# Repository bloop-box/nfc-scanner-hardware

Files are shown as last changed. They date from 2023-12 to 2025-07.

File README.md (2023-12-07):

# Bloop NFC Scanner Hardware



3D Render

[Documentation](https://bloop-box.github.io/nfc-scanner-hardware)

Connect an RC522 based NFC-Reader to your computer using USB

The project is based around a Raspberry Pi [RP2040](https://www.raspberrypi.com/documentation/microcontrollers/rp2040.html) microcontroller. It would have been possible to solve this with a much simpler controller but availability and pricing at the time of development as well as ease of use made the RP2040 with built in USB the best choice. 

The board is designed using KiCAD 6 with production and assembly by JLCPCB in mind. All parts are selected to be available from JLCPCB at the time of writing and as many parts as possible are used from their basic library.

## Case
A simple case design can be found in the case subfolder. It fits when the two boards are connected with standard angled 2.54mm pitch connectors as seen in the picture. 

The two halves can be connected with self-tapping, countersunk M3x6 screws

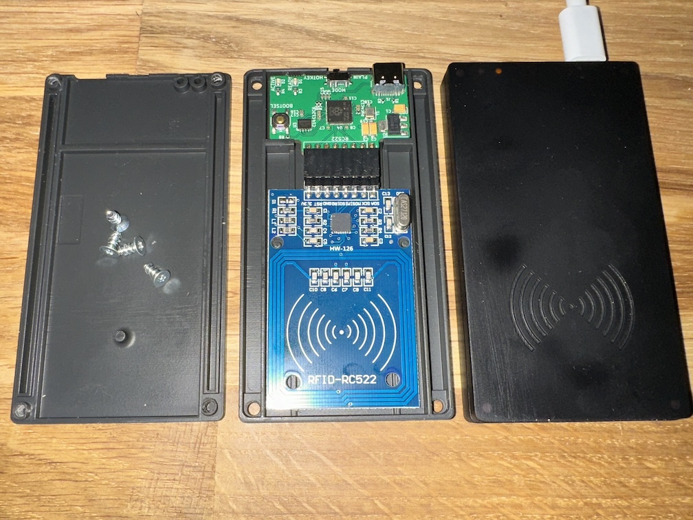
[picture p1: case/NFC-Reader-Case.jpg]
Case


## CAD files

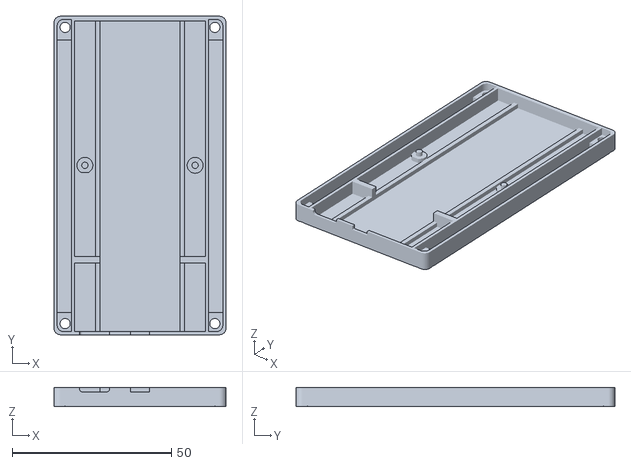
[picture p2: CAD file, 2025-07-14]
case/NFC-Reader-Case-Bottom.stl
54.0 x 100.0 x 6.00

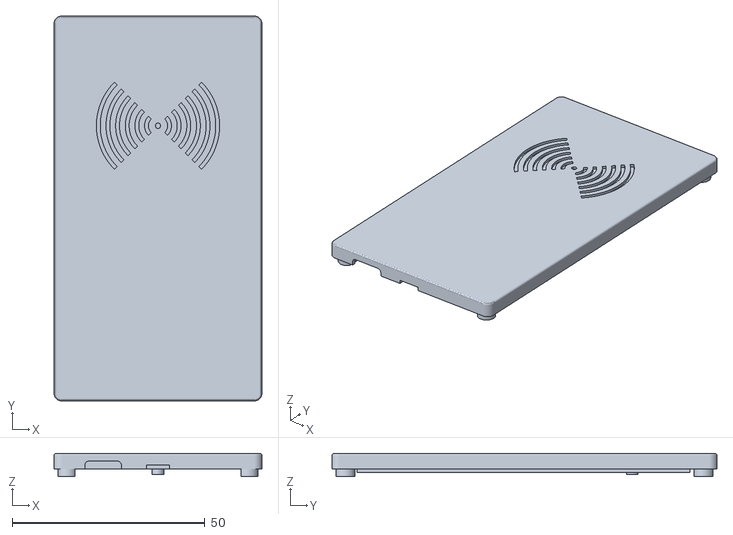
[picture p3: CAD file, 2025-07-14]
case/NFC-Reader-Case-Top.stl
54.0 x 100.0 x 6.00

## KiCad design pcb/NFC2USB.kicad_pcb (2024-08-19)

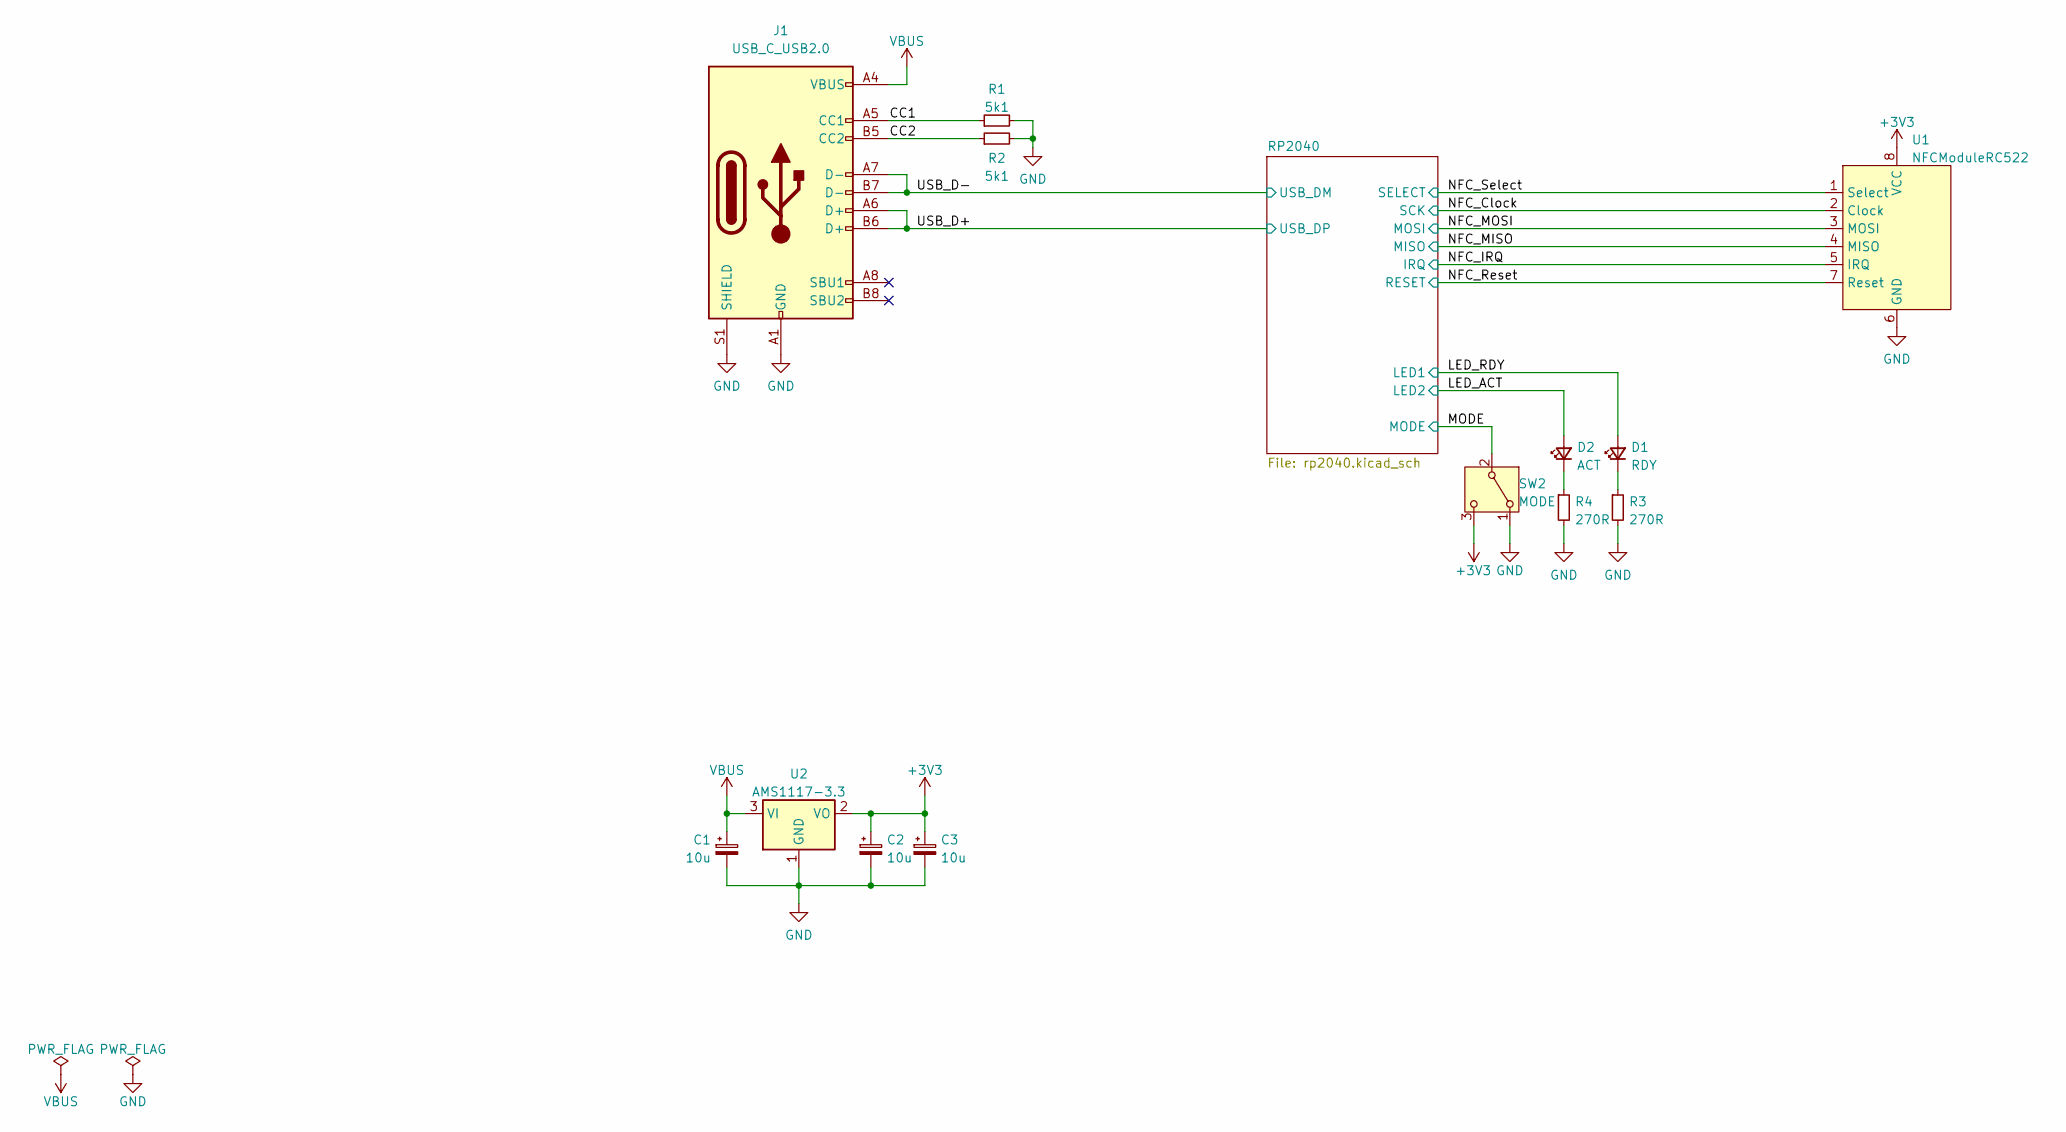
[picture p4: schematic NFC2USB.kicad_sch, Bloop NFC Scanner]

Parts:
C1, C2, C3: 10u; CP_EIA-3216-18_Kemet-A; LCSC C7171
D1: RDY; LED_0603_1608Metric; LCSC C72038
D2: ACT; LED_0603_1608Metric; LCSC C72043
J1: USB_C_USB2.0; USB_C_Receptacle_HRO_TYPE-C-31-M-12; LCSC C2894897
R1, R2: 5k1; R_0402_1005Metric; LCSC C25905
R3, R4: 270R; R_0603_1608Metric; LCSC C22966
SW2: MODE; SW_SPDT_PCM12; LCSC C431541
U1: NFCModuleRC522; PinSocket_1x08_P2.54mm_Vertical; LCSC C2897390
U2: AMS1117-3.3; SOT-223-3_TabPin2; LCSC C6186

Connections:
+3V3: C2.1, C3.1, SW2.3 (C), U1.8 (VCC), U2.2 (VO); also elsewhere on the board
/CC1: J1.A5 (CC1), R1.1
/CC2: J1.B5 (CC2), R2.1
/LED_ACT: D2.2 (A); also elsewhere on the board
/LED_RDY: D1.2 (A); also elsewhere on the board
/MODE: SW2.2 (B); also elsewhere on the board
/NFC_Clock: U1.2 (Clock); also elsewhere on the board
/NFC_IRQ: U1.5 (IRQ); also elsewhere on the board
/NFC_MISO: U1.4 (MISO); also elsewhere on the board
/NFC_MOSI: U1.3 (MOSI); also elsewhere on the board
/NFC_Reset: U1.7 (Reset); also elsewhere on the board
/NFC_Select: U1.1 (Select); also elsewhere on the board
/USB_D+: J1.A6 (D+), J1.B6 (D+); also elsewhere on the board
/USB_D-: J1.A7 (D-), J1.B7 (D-); also elsewhere on the board
GND: C1.2, C2.2, C3.2, J1.A1 (GND), J1.A12 (GND), J1.B1 (GND), J1.B12 (GND), J1.S1 (SHIELD), R1.2, R2.2, R3.2, R4.2, SW2.1 (A), U1.6 (GND), U2.1 (GND); also elsewhere on the board
unnamed: D1.1 (K), R3.1
unnamed: D2.1 (K), R4.1
VBUS: C1.1, J1.A4 (VBUS), J1.A9 (VBUS), J1.B4 (VBUS), J1.B9 (VBUS), U2.3 (VI)

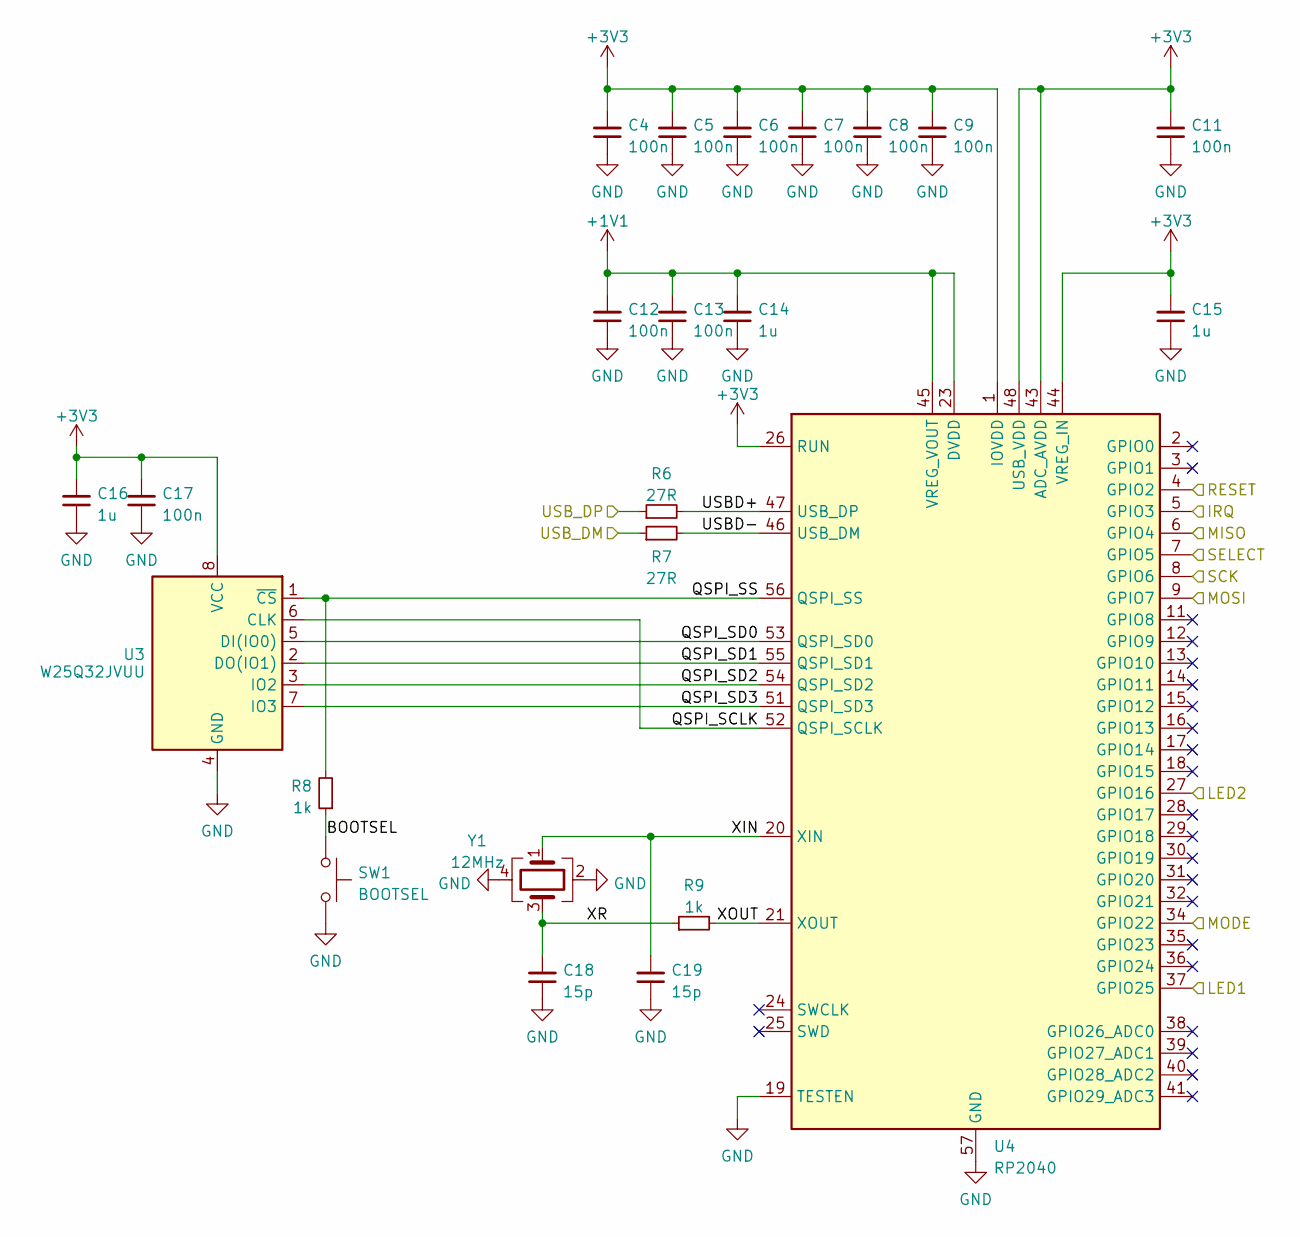
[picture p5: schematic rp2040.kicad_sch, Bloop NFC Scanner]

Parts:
C4, C5, C6, C7, C8, C9, C11, C12, C13, C17: 100n; C_0402_1005Metric; LCSC C1525
C14, C15, C16: 1u; C_0402_1005Metric; LCSC C52923
C18, C19: 15p; C_0402_1005Metric; LCSC C1548
R6, R7: 27R; R_0402_1005Metric; LCSC C25100
R8, R9: 1k; R_0402_1005Metric; LCSC C11702
SW1: BOOTSEL; SW_SPST_TL3342; LCSC C318884
U3: W25Q32JVUU; USON8 (3x4); LCSC C2999380
U4: RP2040; QFN-56-1EP_7x7mm_P0.4mm_EP3.2x3.2mm; LCSC C2040
Y1: 12MHz; Crystal_SMD_3225-4Pin_3.2x2.5mm; LCSC C9002

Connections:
+1V1: C12.2, C13.2, C14.2, U4.23 (DVDD), U4.45 (VREG_VOUT), U4.50 (DVDD)
+3V3: C4.2, C5.2, C6.2, C7.2, C8.2, C9.2, C11.2, C15.2, C16.2, C17.2, U3.8 (VCC), U4.1 (IOVDD), U4.10 (IOVDD), U4.22 (IOVDD), U4.26 (RUN), U4.33 (IOVDD), U4.42 (IOVDD), U4.43 (ADC_AVDD), U4.44 (VREG_IN), U4.48 (USB_VDD), U4.49 (IOVDD); also elsewhere on the board
/LED_ACT: U4.27 (GPIO16); also elsewhere on the board
/LED_RDY: U4.37 (GPIO25); also elsewhere on the board
/MODE: U4.34 (GPIO22); also elsewhere on the board
/NFC_Clock: U4.8 (GPIO6); also elsewhere on the board
/NFC_IRQ: U4.5 (GPIO3); also elsewhere on the board
/NFC_MISO: U4.6 (GPIO4); also elsewhere on the board
/NFC_MOSI: U4.9 (GPIO7); also elsewhere on the board
/NFC_Reset: U4.4 (GPIO2); also elsewhere on the board
/NFC_Select: U4.7 (GPIO5); also elsewhere on the board
/RP2040/BOOTSEL: R8.1, SW1.1
/RP2040/QSPI_SCLK: U3.6 (CLK), U4.52 (QSPI_SCLK)
/RP2040/QSPI_SD0: U3.5 (DI(IO0)), U4.53 (QSPI_SD0)
/RP2040/QSPI_SD1: U3.2 (DO(IO1)), U4.55 (QSPI_SD1)
/RP2040/QSPI_SD2: U3.3 (IO2), U4.54 (QSPI_SD2)
/RP2040/QSPI_SD3: U3.7 (IO3), U4.51 (QSPI_SD3)
/RP2040/QSPI_SS: R8.2, U3.1 (~CS), U4.56 (QSPI_SS)
/RP2040/USBD+: R6.2, U4.47 (USB_DP)
/RP2040/USBD-: R7.2, U4.46 (USB_DM)
/RP2040/XIN: C19.2, U4.20 (XIN), Y1.1
/RP2040/XOUT: R9.2, U4.21 (XOUT)
/RP2040/XR: C18.2, R9.1, Y1.3
/USB_D+: R6.1; also elsewhere on the board
/USB_D-: R7.1; also elsewhere on the board
GND: C4.1, C5.1, C6.1, C7.1, C8.1, C9.1, C11.1, C12.1, C13.1, C14.1, C15.1, C16.1, C17.1, C18.1, C19.1, SW1.2, U3.4 (GND), U4.19 (TESTEN), U4.57 (GND), Y1.2, Y1.4; also elsewhere on the board

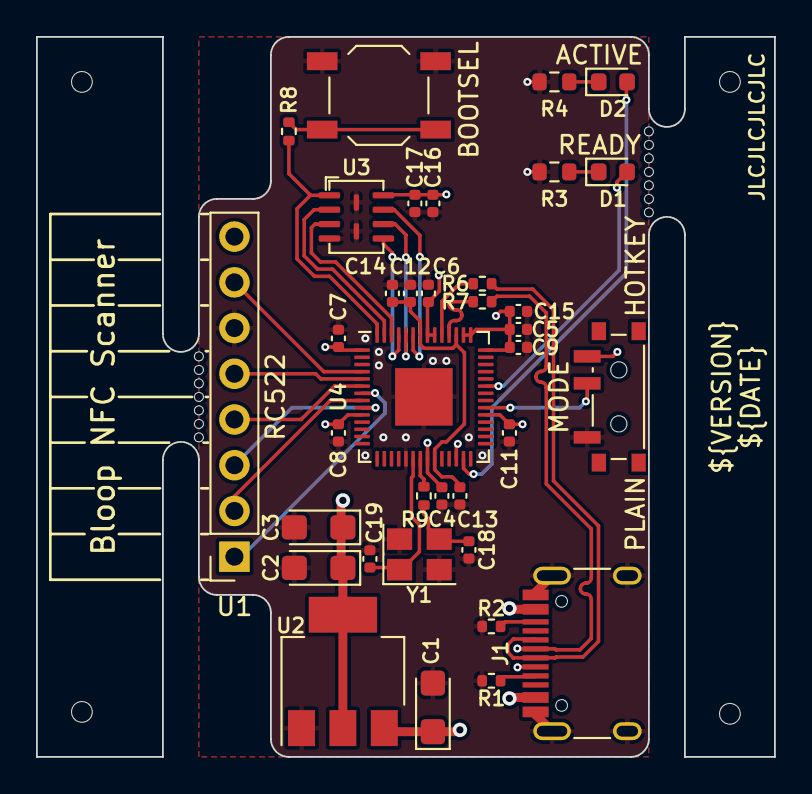
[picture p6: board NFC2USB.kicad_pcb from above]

Board: 4 copper layers, 41.0 x 40.0 mm, 38 parts (0 on the bottom side), 31 nets.

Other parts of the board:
mouse-bite-2mm-slot, mouse-bite-2mm-slot#2: VAL**; mouse-bite-2x5mm-slot-onesided-v2

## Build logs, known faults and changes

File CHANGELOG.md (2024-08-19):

# Changelog

## [1.1.1](https://github.com/bloop-box/nfc-scanner-hardware/compare/v1.1.0...v1.1.1) (2024-08-19)

### Bug Fixes

* add part number for connector ([bab07bb](https://github.com/bloop-box/nfc-scanner-hardware/commit/bab07bbc806345245da13e44c615cc944e2ff816))

## [1.1.0](https://github.com/bloop-box/nfc-scanner-hardware/compare/v1.0.0...v1.1.0) (2023-10-01)

### Features

* add case ([ed1286f](https://github.com/bloop-box/nfc-scanner-hardware/commit/ed1286f51be7c530538ce8dc1104d3dc5748daa6))
* add silkscreen to LEDs and switch ([4b10cee](https://github.com/bloop-box/nfc-scanner-hardware/commit/4b10ceeb942b80ad5307ca541fcebc72cb1d58d2))
* switch LED colors ([2c6a702](https://github.com/bloop-box/nfc-scanner-hardware/commit/2c6a70254306e7911c4967f438318f7faee4ad78))

### Bug Fixes

* case design ([1c09843](https://github.com/bloop-box/nfc-scanner-hardware/commit/1c09843d99eaee1dcc8fff6ef2871743e6540c7f))
* change mouse bites position, add silkscreen ([dfeacb9](https://github.com/bloop-box/nfc-scanner-hardware/commit/dfeacb963f0e60fbaf2108bd07d88693f23c261b))
* move mouse bites away from mode switch ([20b4274](https://github.com/bloop-box/nfc-scanner-hardware/commit/20b427481adfecc08890d7bfbc8925a71b1304e6))

## 1.0.0 (2023-04-17)

### Features

* change flash footprint ([5cb30ff](https://github.com/bloop-box/nfc-scanner-hardware/commit/5cb30ff849db8f0fa7317893f51f6d6915c3a9d4))
* initial commit ([9a0e1b6](https://github.com/bloop-box/nfc-scanner-hardware/commit/9a0e1b6b96b0e62c7939543861680c80d79f5cf1))

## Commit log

2023-04-16 feat: initial commit
    [NFC2USB.kicad_pcb, NFC2USB.kicad_sch, rp2040.kicad_sch]
2023-04-16 style: symbol positioning
    [NFC2USB.kicad_sch]
2023-04-16 feat: change flash footprint
    [NFC2USB.kicad_pcb, NFC2USB.kicad_sch, rp2040.kicad_sch]
2023-04-17 style: move LEDs
    [NFC2USB.kicad_pcb]
2023-04-17 style: update Titles
    [NFC2USB.kicad_pcb, NFC2USB.kicad_sch, rp2040.kicad_sch]
2023-05-02 feat: switch LED colors
    Switching the Activity and Ready LEDs for visibility reasons
    [NFC2USB.kicad_sch]
2023-05-02 feat: add silkscreen to LEDs and switch
    [NFC2USB.kicad_pcb]
2023-05-03 fix: move mouse bites away from mode switch
    [NFC2USB.kicad_pcb]
2023-07-30 feat: add case
    [NFC-Reader-Case-Bottom.stl, NFC-Reader-Case-Top.stl]
2023-10-01 fix: change mouse bites position, add silkscreen
    This commit includes the switch to KiCad 7 which is why there are so many unrelated changes in the files
    The mousebites were moved away from the mode switch
    Silkscreen text was added for mode switch and LEDs
    [NFC2USB.kicad_pcb, NFC2USB.kicad_sch, rp2040.kicad_sch]
2023-10-01 fix: case design
    Fixing a few things noticed after getting a test print: widened the hole for the mode switch by 1mm in each direction, thickened the material over the LEDs to 0.5mm and tightened the screw holes by 0.2mm
    [NFC-Reader-Case-Bottom.stl, NFC-Reader-Case-Top.stl]
2023-12-07 docs: screws
2023-12-07 docs: update case picture
2024-08-19 chore: update to KiCad 8
    [NFC2USB.kicad_pcb, NFC2USB.kicad_sch, rp2040.kicad_sch]
2024-08-19 fix: add part number for connector
    [NFC2USB.kicad_pcb, NFC2USB.kicad_sch]
2024-08-19 docs: replace 3d model for connector
    [NFC2USB.kicad_pcb]
2025-07-14 fix: add 0.5mm to case height
    The latest RC522 modules have a different crystal which is slightly higher. This change makes the modules fit again.
    [NFC-Reader-Case-Bottom.stl, NFC-Reader-Case-Top.stl]
